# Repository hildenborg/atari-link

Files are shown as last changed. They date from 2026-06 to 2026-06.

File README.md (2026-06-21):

## About
The purpose of Atari-Link is to give developers using [m68k-atari-dev toolchain](https://github.com/hildenborg/m68k-atari-dev) the possibillity of developing for real Atari computers the same way they are used to target the Hatari emulator.  
If you aren't a developer and only want a ACSI SD-Card hard disk emulator, then there are many other options with better support.  
The [wiki](https://github.com/hildenborg/atari-link/wiki) is recommended for deeper information  

## Hardware
The hardware is designed in KiCad and the project can be found in the "kicad" directory.  
It is designed to be "easy" to build by hand, and the wiki have more information about that.

## Firmware
The hardware is based around the Raspberry Pico and the formware source is in the "firmware" directory.  
The project is dependent on a submodule, so do not forget to do `git submodule init` and `git submodule update` after cloning this git repository.  

## Setup
If you have built the hardware, and just want to get going, then download [atari-link.zip](https://github.com/hildenborg/atari-link/releases/download/Release1_1/atari_link.zip) and extract its contents.  
Flash the Pico with "atari_link.uf2" and put "config.txt, "tos32mb_ahdi5_boot.img" and "tos32mb_gdbsrv.img" on a FAT32 formatted SD-card.  
This will set you up with a development system that should work on pretty much anything Atari have made.  
You may need to edit the "config.txt" file if you have other hard drives connected, so there aren't any device id collision.  
The hard disk images in the release is TOS 32MB formatted images so they should work on just about anything.  
The "config.txt" in the release is set up so the "tos32mb_ahdi5_boot.img" disk image is not seen by the PC and the "tos32mb_gdbsrv.img" is read-only by the Atari. The "tos32mb_gdbsrv.img" is visible on the PC as a USB drive and files written to it are immediately accessible on the Atari.  
NOTE: Even TOS formatted hard disk images are accessible to the PC as a USB drive. There's a [wiki page](https://github.com/hildenborg/atari-link/wiki/ProblemsSolutions) that describes how it works.

## Usage
The "extras" directory contains a "hello world" example using VsCode and Atari-Link with m68k-atari-dev toolchain.  
This example works exactly the same as the "vscode_hatari" example in the m68k-atari-dev examples.  
After having set up your Atari-Link with firmware and a SD-Card with the released images, you should now be able to start your atari and have a C and D drive (you may have to install the D drive).  
The D drive is the drive that appears as a USB drive on your PC. This is specified in the "config.txt" file that came with the disk images.  
On the D drive there is "gdbsrv.ttp" which you start with "--multi hello.prg" arguments.  
On your PC, execute "./vscode.sh" and in VsCode, press "Shoft-Ctrl-B" to build and "F5" to execute on your atari.  

## License:
This project is MIT licensed.  
The submodule: [no-OS-FatFS-SD-SPI-RPi-Pico](https://github.com/carlk3/no-OS-FatFS-SD-SPI-RPi-Pico) is a separate project and is Apache-2.0 licensed.

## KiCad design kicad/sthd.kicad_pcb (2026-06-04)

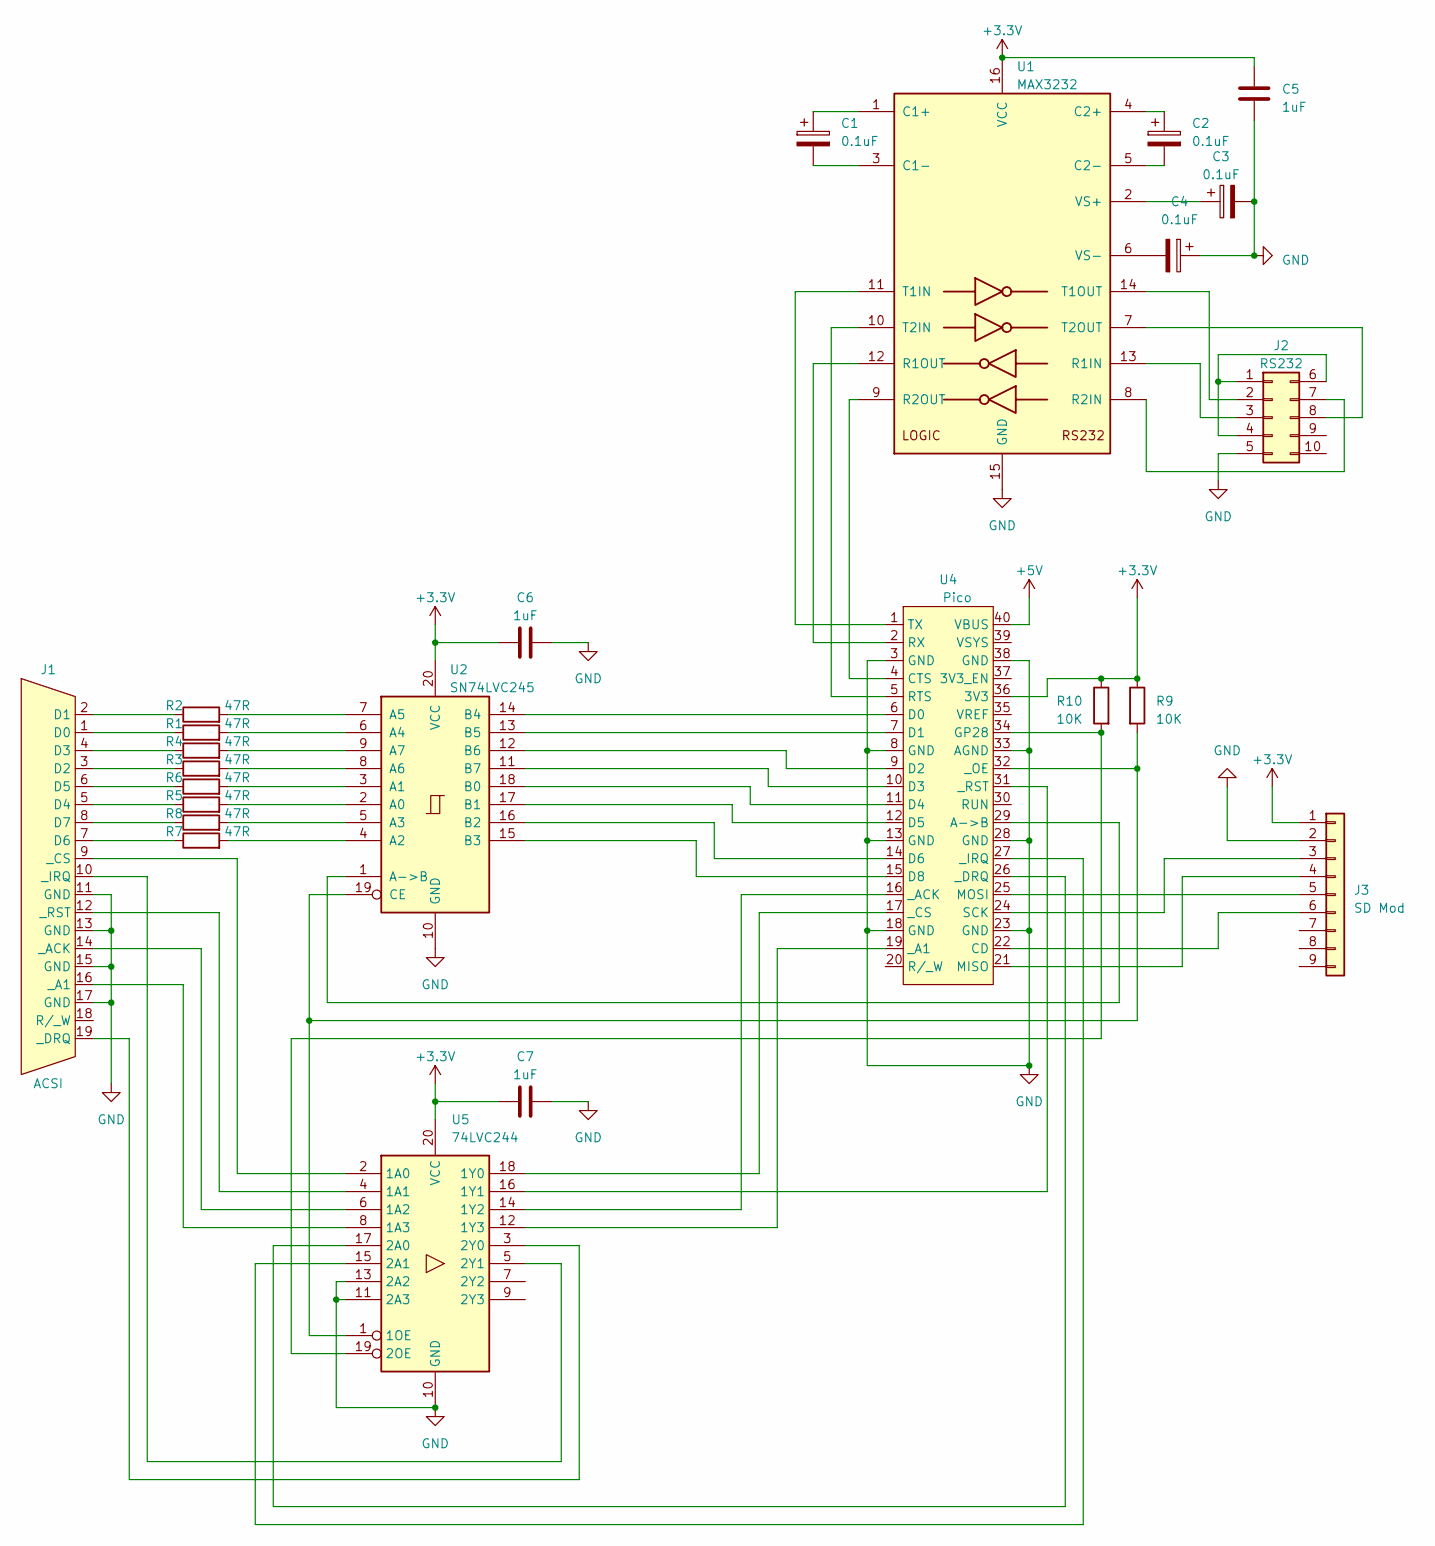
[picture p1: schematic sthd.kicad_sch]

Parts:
C1, C2, C3, C4: 0.1uF; CP_Radial_D5.0mm_P2.00mm
C5, C6, C7: 1uF; C_Disc_D5.0mm_W2.5mm_P5.00mm
J1: ACSI; DB19
J2: RS232; IDC-Header_2x05_P2.54mm_Vertical
J3: SD Mod; PinHeader_1x09_P2.54mm_Vertical
R1, R2, R3, R4, R5, R6, R7, R8: 47R; R_Axial_DIN0207_L6.3mm_D2.5mm_P10.16mm_Horizontal
R9, R10: 10K; R_Axial_DIN0207_L6.3mm_D2.5mm_P10.16mm_Horizontal
U1: MAX3232; DIP-16_W7.62mm
U2: SN74LVC245; DIP-20_W7.62mm
U4: Pico
U5: 74LVC244; DIP-20_W7.62mm

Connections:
+3.3V: C5.1, C6.1, C7.1, J3.1, R9.1, R10.1, U1.16 (VCC), U2.20 (VCC), U4.36 (3V3), U5.20 (VCC)
+5V: U4.40 (VBUS)
GND: C3.2, C4.1, C5.2, C6.2, C7.2, J1.11 (GND), J1.13 (GND), J1.15 (GND), J1.17 (GND), J2.5, J3.2, U1.15 (GND), U2.10 (GND), U4.3 (GND), U4.8 (GND), U4.13 (GND), U4.18 (GND), U4.23 (GND), U4.28 (GND), U4.33 (AGND), U4.38 (GND), U5.10 (GND), U5.11 (2A3), U5.13 (2A2)
unnamed: J1.1 (D0), R1.1
unnamed: J1.2 (D1), R2.1
unnamed: J1.3 (D2), R3.1
unnamed: J1.4 (D3), R4.1
unnamed: J1.5 (D4), R5.1
unnamed: J1.6 (D5), R6.1
unnamed: J1.7 (D6), R7.1
unnamed: J1.8 (D7), R8.1
unnamed: J1.16 (_A1), U5.8 (1A3)
unnamed: J1.14 (_ACK), U5.6 (1A2)
unnamed: J1.9 (_CS), U5.2 (1A0)
unnamed: J1.19 (_DRQ), U5.3 (2Y0)
unnamed: J1.10 (_IRQ), U5.5 (2Y1)
unnamed: J1.12 (_RST), U5.4 (1A1)
unnamed: J2.1, J2.4, J2.6
unnamed: J2.2, U1.14 (T1OUT)
unnamed: J2.3, U1.13 (R1IN)
unnamed: J2.7, U1.8 (R2IN)
unnamed: J2.8, U1.7 (T2OUT)
unnamed: J3.3, U4.24 (SCK)
unnamed: J3.4, U4.21 (MISO)
unnamed: J3.5, U4.25 (MOSI)
unnamed: J3.6, U4.22 (CD)
unnamed: C1.1, U1.1 (C1+)
unnamed: C1.2, U1.3 (C1-)
unnamed: C2.1, U1.4 (C2+)
unnamed: C2.2, U1.5 (C2-)
unnamed: U1.12 (R1OUT), U4.2 (RX)
unnamed: U1.9 (R2OUT), U4.4 (CTS)
unnamed: U1.11 (T1IN), U4.1 (TX)
unnamed: U1.10 (T2IN), U4.5 (RTS)
unnamed: C3.1, U1.2 (VS+)
unnamed: C4.2, U1.6 (VS-)
unnamed: R5.2, U2.2 (A0)
unnamed: R6.2, U2.3 (A1)
unnamed: R7.2, U2.4 (A2)
unnamed: R8.2, U2.5 (A3)
unnamed: R1.2, U2.6 (A4)
unnamed: R2.2, U2.7 (A5)
unnamed: R3.2, U2.8 (A6)
unnamed: R4.2, U2.9 (A7)
unnamed: U2.1 (A->B), U4.29 (A->B)
unnamed: U2.18 (B0), U4.11 (D4)
unnamed: U2.17 (B1), U4.12 (D5)
unnamed: U2.16 (B2), U4.14 (D6)
unnamed: U2.15 (B3), U4.15 (D8)
unnamed: U2.14 (B4), U4.6 (D0)
unnamed: U2.13 (B5), U4.7 (D1)
unnamed: U2.12 (B6), U4.9 (D2)
unnamed: U2.11 (B7), U4.10 (D3)
unnamed: R9.2, U2.19 (CE), U4.32 (_OE), U5.1 (1OE)
unnamed: R10.2, U4.34 (GP28), U5.19 (2OE)
unnamed: U4.19 (_A1), U5.12 (1Y3)
unnamed: U4.16 (_ACK), U5.14 (1Y2)
unnamed: U4.17 (_CS), U5.18 (1Y0)
unnamed: U4.26 (_DRQ), U5.17 (2A0)
unnamed: U4.27 (_IRQ), U5.15 (2A1)
unnamed: U4.31 (_RST), U5.16 (1Y1)

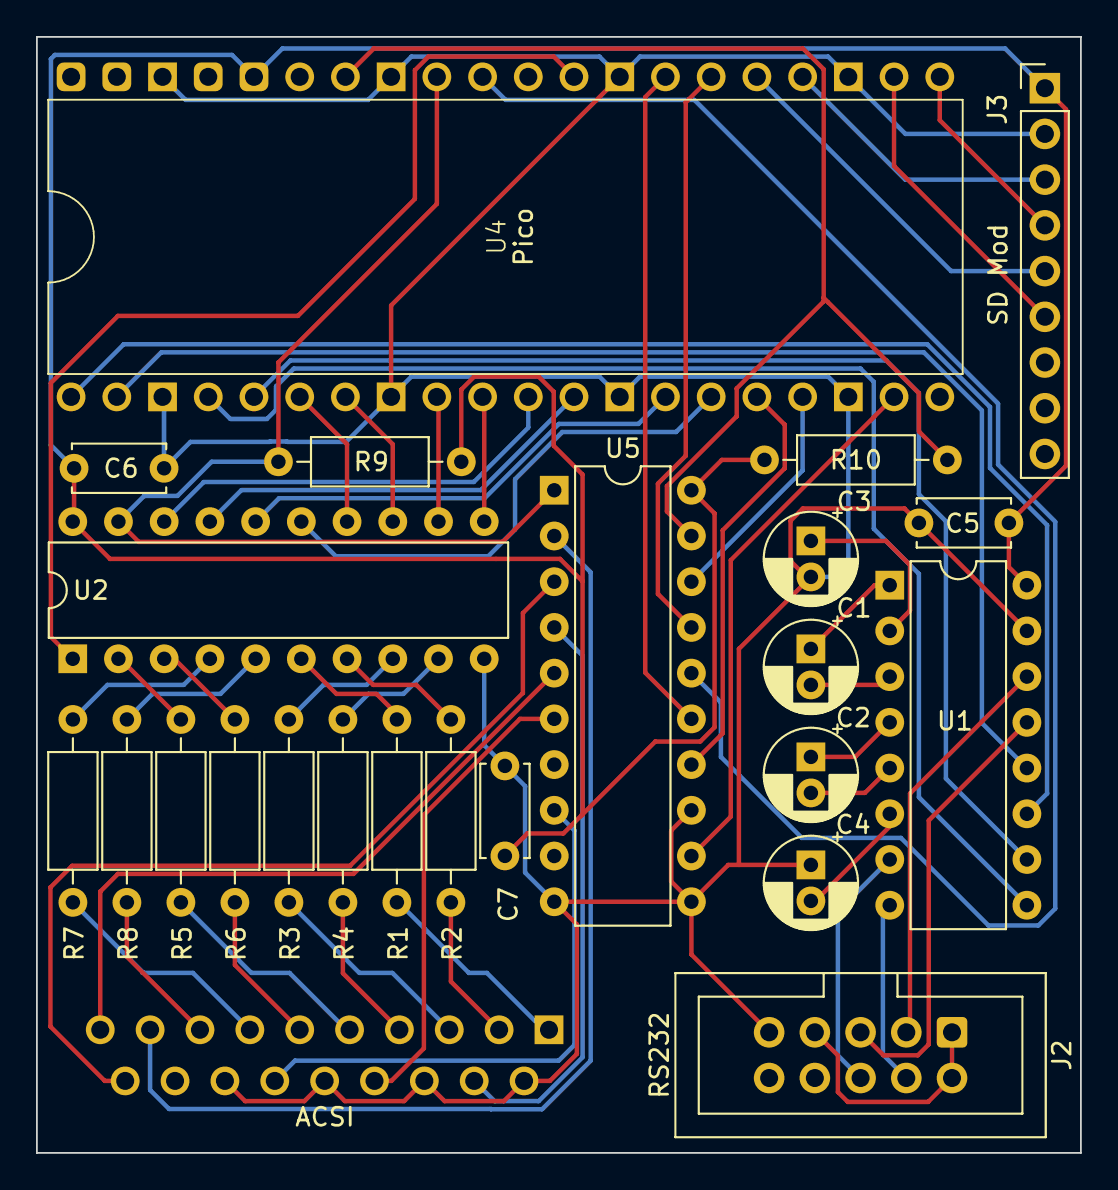
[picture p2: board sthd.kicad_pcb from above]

Board: 2 copper layers, 58.0 x 62.0 mm, 24 parts (1 on the bottom side), 60 nets.

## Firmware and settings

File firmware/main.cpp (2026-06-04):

#define NO_PICO_LED

#include <stdio.h>
#include <string.h>
#include <pico/stdlib.h>
#include <pico/binary_info.h>
#include <pico/multicore.h>
#include <ff.h>
#include <hw_config.h>
#include "acsi.h"
#include "image.h"
#include "Usb/usb.h"
//#include "FatFs/ff.h"
#include "config.h"

/*
	Bugs:
	SCSI UNIT ATTENTION doesn't seem to work on pc side.
	Extended partitions are not exposed to USB - this is caused by inconsistencies between how Atari and
	other operating systems handle sector clusters. Can be solved by using drivers that do the right thing.

	Known issues:
	Having both ACSI and USB as WRITEABLE works as long as you are careful to not write to disk from
		both sides at the same time. As should be obvious. This is impossible to fix, don't even go there!
		To make mathers worse, Windows wants to create a "System Volume Information" folder on every drive
		it has access to, even USB sticks. And then Windows frequently updates this folder so it is doomed
		to destroy any drive that have both sides as WRITEABLE.
		One way to avoit this, is to create an empty file in the root of every drive and call it
		"System Volume Information", and Windows will be unable to write that information.
		
	Testing:
	Need to test a lot more HD configurations.
	ICD test drive writes to boot sector and destroys drive... Could have been a virus on my test drive...
	
	Cleanup:
	image.h and image.cpp contains a many classes that should be in their own files.
	usb.h and usb.cpp contains a serial class that should have its own files.
	Maybe a better folder hierarchy?

	Optimizations:
	Double buffered DMA for acsi read/write
		https://github.com/raspberrypi/pico-examples/blob/master/pio/logic_analyser/logic_analyser.c
*/

namespace
{
	static Config config;
	static DriveCollection drives;
	static Acsi acsi;
	static int dbg_code = 0;
};

	
void core1_main(void)
{	
	acsi.Start();
}

void SetDbgCode(int v)
{
	dbg_code = v;
}

void ShowDbgCode(int led_pin)
{
	while(true)
	{
		// led unlit for two seconds
		gpio_put(led_pin, 0);
		busy_wait_ms(2000);
		int a = 0;
		for (int i = 0; i <= 4; ++i)
		{
			int b = (dbg_code >> i) & 1;	// new state of led
			if (a == b)
			{
				// Next state is the same, short blink to mark
				gpio_put(led_pin, 1 - a);
				busy_wait_ms(250);
			}
			gpio_put(led_pin, b);
			busy_wait_ms(500);
			a = b;
		}
	}
}

int main(int argc, char **argv)
{
	int result = -1;
    const uint LED_PIN = PICO_DEFAULT_LED_PIN;
    gpio_init(LED_PIN);
    gpio_set_dir(LED_PIN, GPIO_OUT);
	gpio_put(LED_PIN, 0);

	bi_decl(bi_program_description("Atari ST programming help."));

    sd_card_t *pSD = sd_get_by_num(0);
	FRESULT mountResult = f_mount(&pSD->fatfs, pSD->pcName, 1);	// Mounts the SD card at path "".
	if (FR_OK == mountResult)
	{
		SetDbgCode(1);
		if (config.Load("config.txt"))
		{
			SetDbgCode(2);
			for (int i = 0; i < config.GetDrives(); ++i)
			{
				if (false == drives.LoadImage(config.GetDrive(i)))
				{
					// Failed!
				}
			}
			Serial serial(&config);
			InitUSB(drives.GetUSBInterface());
			if (acsi.Init(drives.GetAcsiInterface(), config.GetBaseId()))
			{
				SetDbgCode(3);
				multicore_launch_core1(core1_main);
				USB_main();
				acsi.Stop();
				SetDbgCode(15); // Dbg code 1111
			}
		}
		f_unmount(pSD->pcName);
	}
	ShowDbgCode(LED_PIN);
	return result;
}	

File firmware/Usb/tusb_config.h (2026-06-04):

/*
 * The MIT License (MIT)
 *
 * Copyright (c) 2019 Ha Thach (tinyusb.org)
 *
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
 */

#ifndef _TUSB_CONFIG_H_
#define _TUSB_CONFIG_H_

#ifdef __cplusplus
 extern "C" {
#endif

//--------------------------------------------------------------------
// COMMON CONFIGURATION
//--------------------------------------------------------------------

// defined by board.mk
#ifndef CFG_TUSB_MCU
  #error CFG_TUSB_MCU must be defined
#endif

// RHPort number used for device can be defined by board.mk, default to port 0
#ifndef BOARD_DEVICE_RHPORT_NUM
  #define BOARD_DEVICE_RHPORT_NUM     0
#endif

// RHPort max operational speed can defined by board.mk
// Default to Highspeed for MCU with internal HighSpeed PHY (can be port specific), otherwise FullSpeed
#ifndef BOARD_DEVICE_RHPORT_SPEED
  #if (CFG_TUSB_MCU == OPT_MCU_LPC18XX || CFG_TUSB_MCU == OPT_MCU_LPC43XX || CFG_TUSB_MCU == OPT_MCU_MIMXRT10XX || \
       CFG_TUSB_MCU == OPT_MCU_NUC505  || CFG_TUSB_MCU == OPT_MCU_CXD56)
    #define BOARD_DEVICE_RHPORT_SPEED   OPT_MODE_HIGH_SPEED
  #else
    #define BOARD_DEVICE_RHPORT_SPEED   OPT_MODE_FULL_SPEED
  #endif
#endif

// Device mode with rhport and speed defined by board.mk
#if   BOARD_DEVICE_RHPORT_NUM == 0
  #define CFG_TUSB_RHPORT0_MODE     (OPT_MODE_DEVICE | BOARD_DEVICE_RHPORT_SPEED)
#elif BOARD_DEVICE_RHPORT_NUM == 1
  #define CFG_TUSB_RHPORT1_MODE     (OPT_MODE_DEVICE | BOARD_DEVICE_RHPORT_SPEED)
#else
  #error "Incorrect RHPort configuration"
#endif

// This example doesn't use an RTOS
//#define CFG_TUSB_OS               OPT_OS_NONE

// CFG_TUSB_DEBUG is defined by compiler in DEBUG build
// #define CFG_TUSB_DEBUG           0

/* USB DMA on some MCUs can only access a specific SRAM region with restriction on alignment.
 * Tinyusb use follows macros to declare transferring memory so that they can be put
 * into those specific section.
 * e.g
 * - CFG_TUSB_MEM SECTION : __attribute__ (( section(".usb_ram") ))
 * - CFG_TUSB_MEM_ALIGN   : __attribute__ ((aligned(4)))
 */
#ifndef CFG_TUSB_MEM_SECTION
#define CFG_TUSB_MEM_SECTION
#endif

#ifndef CFG_TUSB_MEM_ALIGN
#define CFG_TUSB_MEM_ALIGN          __attribute__ ((aligned(4)))
#endif

//--------------------------------------------------------------------
// DEVICE CONFIGURATION
//--------------------------------------------------------------------

#ifndef CFG_TUD_ENDPOINT0_SIZE
#define CFG_TUD_ENDPOINT0_SIZE    64
#endif

//------------- CLASS -------------//
#define CFG_TUD_CDC              1
#define CFG_TUD_MSC              1
#define CFG_TUD_HID              0
#define CFG_TUD_MIDI             0
#define CFG_TUD_VENDOR           0

// CDC FIFO size of TX and RX
#define CFG_TUD_CDC_RX_BUFSIZE   (TUD_OPT_HIGH_SPEED ? 512 : 64)
#define CFG_TUD_CDC_TX_BUFSIZE   (TUD_OPT_HIGH_SPEED ? 512 : 64)
//#define CFG_TUD_CDC_IGNORE_DTR

// MSC Buffer size of Device Mass storage
#define CFG_TUD_MSC_EP_BUFSIZE   16384

#ifdef __cplusplus
 }
#endif

#endif /* _TUSB_CONFIG_H_ */

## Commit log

2026-06-04 setting up repo
    [sthd.kicad_pcb, sthd.kicad_sch]
2026-06-07 Updated project settings.
    [raspberrypi-swd.cfg]
2026-06-10 Correct setting of oe1 and oe2 when startup or reset.
    [acsi.cpp]
2026-06-16 Fixed bug where ACSI emulation randomly would not start after power off and on.
    [acsi.cpp]
